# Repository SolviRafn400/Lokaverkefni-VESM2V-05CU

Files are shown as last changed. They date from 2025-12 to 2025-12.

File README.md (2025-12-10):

# Lokaverkefni-VESM2V-05CU
## íhlutir
* RasberryPi 5
* esp32-s3
* DFPlayer
* speakers
* 2 servo móters
* laser diode
* neopixel ring ljós

## Mótor laser


* 2 Micro Servo Motors (MG90S)
* 1 Laser diode
* Source. ([*alliexpress link hérna*](https://www.aliexpress.com/item/1005006539122837.html#nav-specification))
  
  hugmyndin var að mappa moteranna við myndavél þannig það getur beinið laser á fólk via facial recognition.

## Myndavél


* Picameras V3

  við erum að nota rasberry Py camera V3 handa facial recognition að nota

## audio speakers


* DFPlayer
* Stereo Enclosed Speaker Set
* 1GB SDCard

  við notum DFPlayer með SDCard sem heldur við nokkur sound files af portal turret sem við fundum hér(https://tuna.voicemod.net/search/sounds/portal-turret/).
  við erum svo með tvo sterio hátalara sem ef er of stórt handa 3D Printið þá notum við minni hátalara
  
code:
  from machine import Pin, ADC
  import asyncio
  from dfplayer import DFPlayer
  df = DFPlayer(2)
  df.init(tx=17, rx=16)
  async def main():
    await df.wait_available()
    await df.volume(25)
    for x in range(6):
        if x+1==6:
            await df.volume(30)
            await df.play(1, x+1)
            await asyncio.sleep_ms(1200)
        else:
            await df.volume(25)
            await df.play(1, x+1)
            await asyncio.sleep_ms(1200)  
asyncio.run(main())

## 3D print


* (*insert link or something here*)
* tinkercad
* blender
* svart acrylic málingu

  við notuðum tinkercad handa 3d modelið hjá armana, tannhjólinn og fæturnar. En handa aðal búkinn þurftu við að nota blender því 3D modelið var of flókið handa tinkercad. svo þegar við vorum comin með #d printið þá máluðum við það með svörtum acrylic málingu.
  (*meiri info hér ef hægt*)

## RasberryPi


* RasberryPi 5

  við erum að nota RasberryPi 5 til að halda aðal codeið. hann er téingdur við myndavélinna til að geta leifa facial recognition codið að nota, hann er teingdur við ESP32ið til að tala við móteranna og dfplayeranna.

## Sketch hugmynd


hugmyndin var að búa til turret frá leiknum Portal 2. okkur lángaði að það gæti miðað á fólk með laser og ítt armanna út þegar myndavélinn sá einhvern og látið ljós blikka í armana eins og hann var að skjóta þig. svo lánguðum við að geta teingið við myndavélinna frá símannum með niceguy. 

en út af of littlum tíma og tæknilega erfileika þurftu við að yfirgefa niceguy og ljósin í armanna og og að hafa mótor til að ýta armana út og focusa á facial recognition, laser móteranna og audioið.
facial recognition ai sem við notuðum var voða hægt og erfit að nota. hann var voða laggy og var alltaf að lagga og crasha.

## Loka Myndir





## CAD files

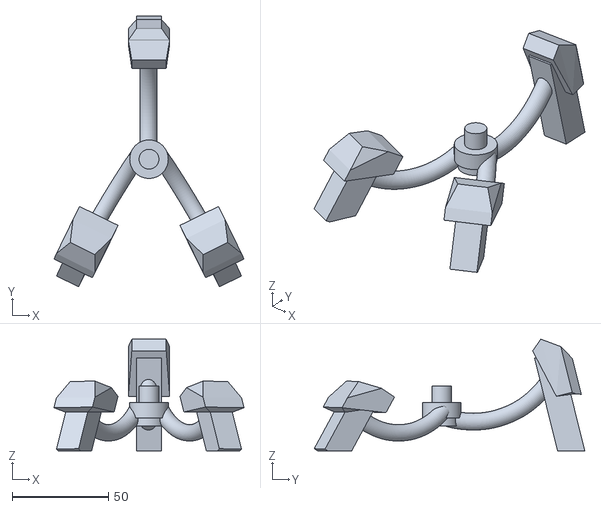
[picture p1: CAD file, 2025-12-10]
Leg.stl
98.7 x 140.6 x 58.0

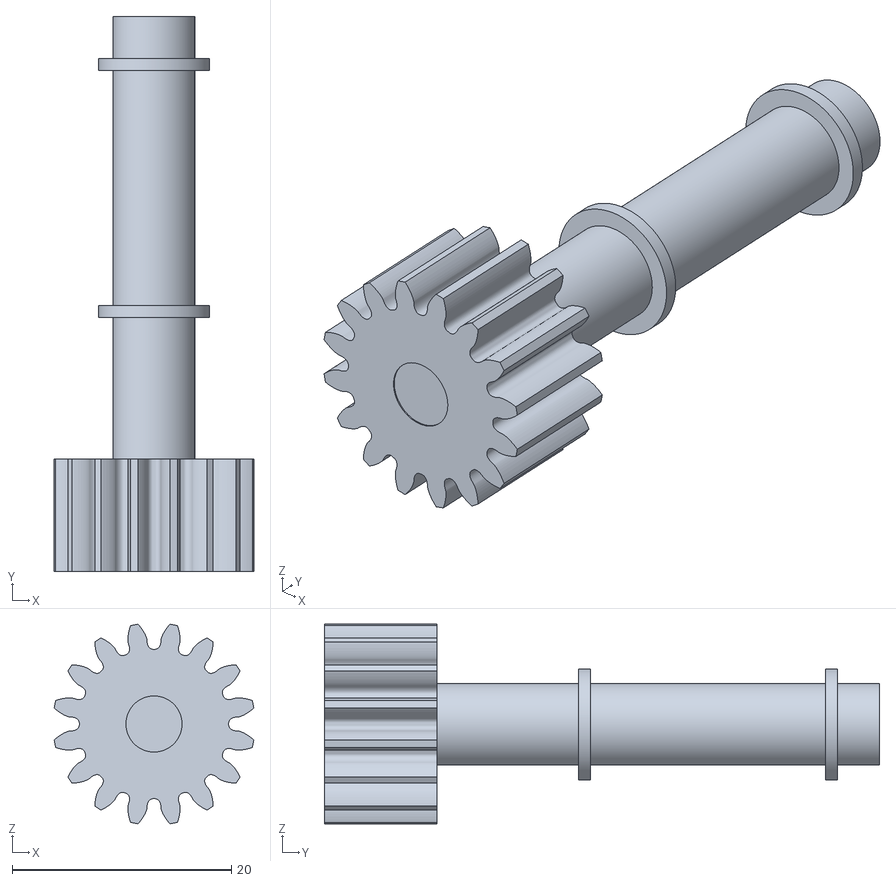
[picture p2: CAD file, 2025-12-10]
Mechanism'.stl
18.2 x 50.6 x 18.2

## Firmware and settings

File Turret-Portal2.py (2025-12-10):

from mqtt_as import MQTTClient, config
import asyncio
import json

from machine import PWM, Pin, Timer, ADC
import machine
from servo import Servo
from time import sleep_ms
import asyncio
import math

y_axis_pin = machine.Pin(48)
y_axis_servo = Servo(y_axis_pin)
y_axis_min = 52
y_axis_max = 112

x_axis_pin = machine.Pin(47)
x_axis_servo = Servo(x_axis_pin)
x_axis_min = 0
x_axis_max = 60

x_axis_servo.write_angle(20)

y_axis_servo.write_angle(82)

# WIFI stillingar
config["ssid"] = "TskoliVESM"
config["wifi_pw"] = "Fallegurhestur"

# MQTT þjónninn
config["server"] = "10.201.48.54" # eða broker.emqx.io (þarf að vera það sama á sendir og móttakara)
config["queue_len"] = 1

# TOPICS
TOPIC = "0205kynning" # Settu fyrstu fjóra stafinu úr kennitölunni þinni stað í X-anna
#TOPIC_2 = "YYYYkynning"
latest_message = None
# Fallið meðhöndlar skilaboð sem berast
async def mottakari(client):
    global latest_message
    async for topic, skilabod, _ in client.queue:
        decoded = skilabod.decode()
        try:
            latest_message = json.loads(decoded)   # parse JSON string into dict
        except json.JSONDecodeError:
            print("Invalid JSON:", decoded)

# Fallið sér um að gerast ákrifandi að topic-um og viðhalda áskriftinni ef tenging tapast
async def askrift(client):
    while True:
        await client.up.wait()
        client.up.clear()
        # Topik-ið (eitt eða fleiri) sem á að gerast áskrifandi að
        await client.subscribe(TOPIC, 1) 
        # await client.subscribe(TOPIC_2, 1) 

cx = 0
cy = 0
person = False
async def print_info():
    global cx, cy, person
    global latest_message
    while True:
        if latest_message:
            has_person = latest_message.get("has_person", False)
            people = latest_message.get("people", [])
            if people:
                center = people[0].get("center", {})
                cx = int(center.get("x"))
                cy = int(center.get("y"))
                person = True
                print(f"Has person: {has_person}, Center: x={cx}, y={cy}")
            else:
                person = False
                print(f"Has person: {has_person}, no people detected")
        await asyncio.sleep(0.2)  # print twice per second

async def x():
    global x_axis_servo
    global x_axis_min
    global x_axis_max
    while True:
        for i in range(x_axis_min,x_axis_max+1):
            x_axis_servo.write_angle(i)
            await asyncio.sleep_ms(10)
        for i in range(x_axis_max,x_axis_min+1,-1):
            x_axis_servo.write_angle(i)
            await asyncio.sleep_ms(10)

async def y():
    global y_axis_servo
    global y_axis_min
    global y_axis_max
    while True:
        for i in range(y_axis_min,y_axis_max+1):
            y_axis_servo.write_angle(i)
            await asyncio.sleep_ms(15)
        for i in range(y_axis_max,y_axis_min+1,-1):
            y_axis_servo.write_angle(i)
            await asyncio.sleep_ms(15)

async def circle():
    global x_axis_servo, y_axis_servo
    global x_axis_min
    global x_axis_max
    global y_axis_min
    global y_axis_max
    x_center = (x_axis_min+x_axis_max)/2   # midpoint for X servo
    y_center = (y_axis_min+y_axis_max)/2   # midpoint for Y servo
    radius = 30     # how far to swing
    step = 0

    while True:
        # parametric circle
        x_angle = int(x_center + radius * math.cos(step))
        y_angle = int(y_center + radius * math.sin(step))
        
        if x_angle > x_axis_min and x_angle < x_axis_max:
            x_axis_servo.write_angle(x_angle)
        if y_angle > y_axis_min and y_angle < y_axis_max:
            y_axis_servo.write_angle(y_angle)

        step += 0.1   # increment angle in radians
        if step > 2*math.pi:
            step = 0

        await asyncio.sleep_ms(20)
def remap(value, in_min, in_max, out_min, out_max):
    # Clamp to input range if needed
    if value < in_min:
        value = in_min
    if value > in_max:
        value = in_max
    
    return (value - in_min) * (out_max - out_min) / (in_max - in_min) + out_min
async def cam_to_motor():
    while True:
        global cx, cy, person
        global x_axis_servo, y_axis_servo
        global x_axis_min
        global x_axis_max
        global y_axis_min
        global y_axis_max
        y_angle = round(remap(cx,0,640,y_axis_min,y_axis_max))
        x_angle = round(remap(cy,0,360,x_axis_min,x_axis_max))
        x_axis_servo.write_angle(x_angle)
        y_axis_servo.write_angle(y_angle)
        print(x_angle,y_angle)
        await asyncio.sleep_ms(50)



async def main(client):
    # tengjast við þráðlausa netið
    await client.connect()
    # búa til task
    asyncio.create_task(askrift(client))
    asyncio.create_task(mottakari(client))
    asyncio.create_task(print_info())
    asyncio.create_task(cam_to_motor())
    while True:
        # Hér kæmi kóði sem á ekki að keyra async, t.d. lesa frá stilliviðnámi
        await asyncio.sleep_ms(0)

# Sýnir ýmsar upplýsingar eins og t.d. varðandi nettenginguna og minnisnotkun  
MQTTClient.DEBUG = True

# Búa til tilvik af MQTTClient og senda inn stillingarnar
client = MQTTClient(config)

try:
    # Ræsa async main fallið og senda þangað tilvik af client-num
    asyncio.run(main(client))
finally:
    client.close()

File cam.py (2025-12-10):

from aiomqtt import Client
import asyncio
import cv2
import time
import json

from picamera2 import Picamera2
from azure.ai.vision.imageanalysis import ImageAnalysisClient
from azure.ai.vision.imageanalysis.models import VisualFeatures
from azure.core.credentials import AzureKeyCredential

MQTT_SERVER = "10.201.48.54"
MQTT_TOPIC = "0205kynning"

endpoint = "endpoint"
key = "key"

vision_client = ImageAnalysisClient(
    endpoint=endpoint,
    credential=AzureKeyCredential(key)
)

picam2 = Picamera2()
cfg = picam2.create_preview_configuration(
    main={"size": (640,360), "format": "RGB888"}
)
picam2.configure(cfg)
picam2.start()

async def analyze_frame(data):
    loop = asyncio.get_running_loop()
    return await loop.run_in_executor(
        None,
        lambda: vision_client.analyze(
            image_data=data,
            visual_features=[VisualFeatures.PEOPLE]
        )
    )

async def send_loop(client):
    while True:
        frame = picam2.capture_array()
        ok, buf = cv2.imencode(".jpg", frame)
        if not ok:
            print("encode failed")
            await asyncio.sleep(1.0)
            continue

        data = buf.tobytes()

        try:
            r = await analyze_frame(data)
        except Exception as e:
            print("azure error:", repr(e))
            await asyncio.sleep(5.0)
            continue

        people = []
        if r.people is not None:
            for p in r.people.list:
                if p.confidence < 0.3:
                    continue
                bb = p.bounding_box
                x = bb.x
                y = bb.y
                w = bb.width
                h = bb.height
                people.append({
                    "center": {"x": x + w/2, "y": y + h/2}
                })

        out = {
            "has_person": len(people) > 0,
            "people": people
        }

        payload = json.dumps(out)
        print("sending:", payload)

        try:
            await client.publish(MQTT_TOPIC, payload)
        except Exception as e:
            print("mqtt error:", repr(e))

        await asyncio.sleep(1.0)

async def main():
    async with Client(MQTT_SERVER) as client:
        await send_loop(client)

try:
    asyncio.run(main())
finally:
    picam2.close()

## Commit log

2025-12-10 Update README with sketch and motor laser details
    Added sections for sketch idea and motor laser components.
2025-12-10 Enhance README with camera section and images
    Added images and expanded section on camera integration.
2025-12-10 Enhance README with project details and images
    Expanded the README with detailed sections on components, 3D printing, and Raspberry Pi usage, including images and descriptions of the project.
